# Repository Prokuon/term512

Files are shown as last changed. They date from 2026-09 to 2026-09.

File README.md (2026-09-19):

# TERM512: CardputerAdv Expansion Kit for AREA512 Firmware

TERM512 is a custom expansion kit for the CardputerAdv, tailored specifically for the [AREA512](https://github.com/engneer-hamachan/area512) firmware. It is designed to reshape the CardputerAdv into a cyberdeck that fully aligns with the visual aesthetics of AREA512, serving as the dedicated physical hardware platform for the project

Of course, this kit is essentially a stylized CapTFT expansion module, and adaptations for other firmwares are always welcome

The kit consists of the following components:

- **Custom-Designed CapTFT Enclosure**: Redesigns the top lid based on [CapTFT V2](https://github.com/Prokuon/CardputerADV_Cap_TFT_V2), and increases the maximum screen opening angle from 120° to 135°;
- **Protective Base**: Secured via two of the LEGO-compatible holes on the bottom of the CardputerAdv. It integrates two latches to lock the screen lid securely in place when closed, along with a lanyard hole;
- **Adjustable Kickstand**: Installed using the remaining two LEGO-compatible holes on the bottom. The hinge damping can be tuned via the adjustment bolt

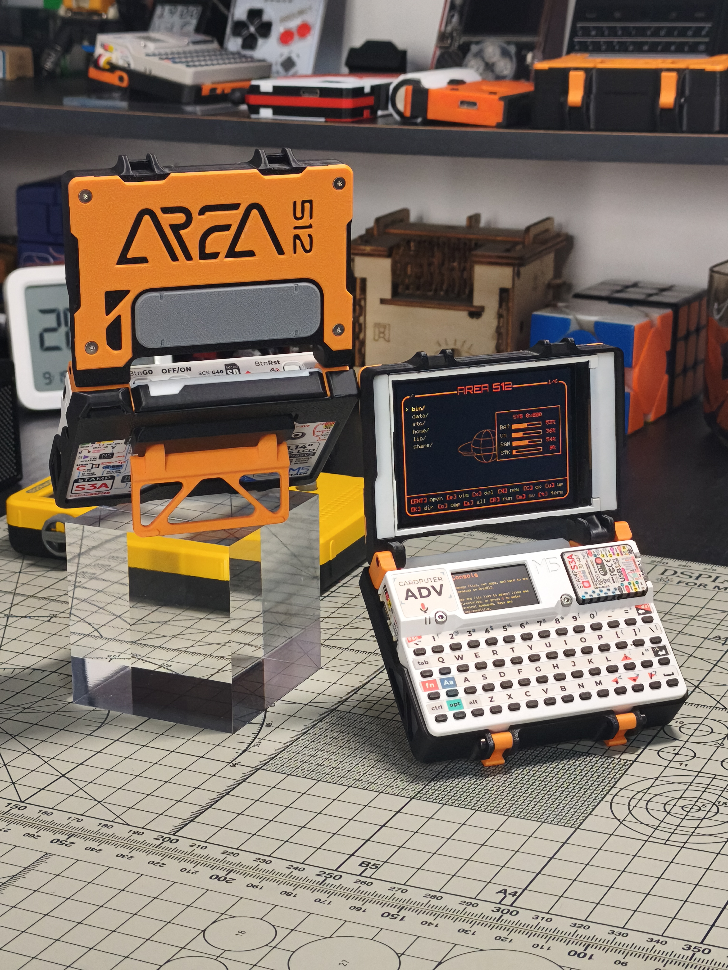
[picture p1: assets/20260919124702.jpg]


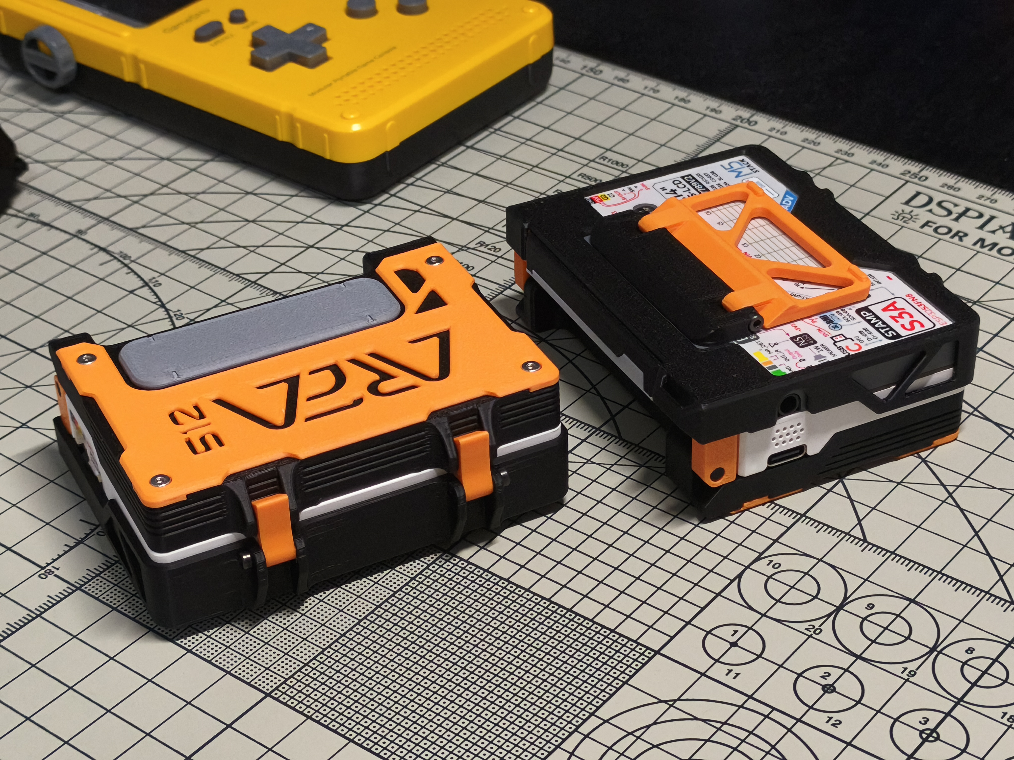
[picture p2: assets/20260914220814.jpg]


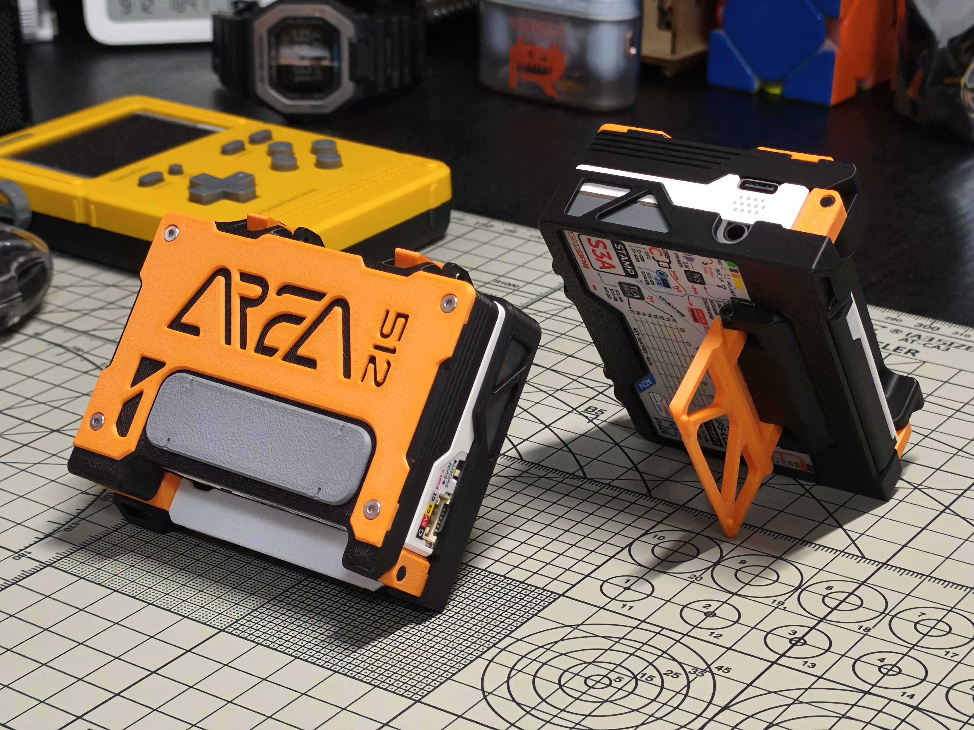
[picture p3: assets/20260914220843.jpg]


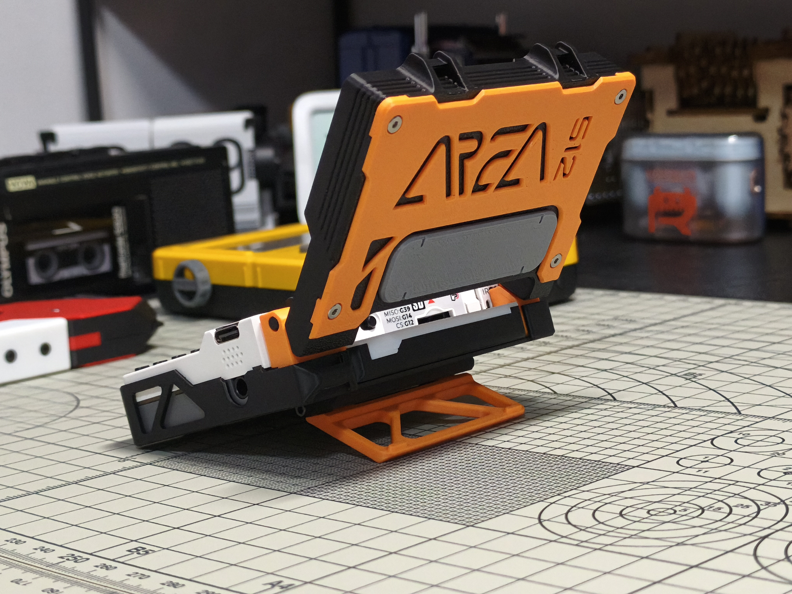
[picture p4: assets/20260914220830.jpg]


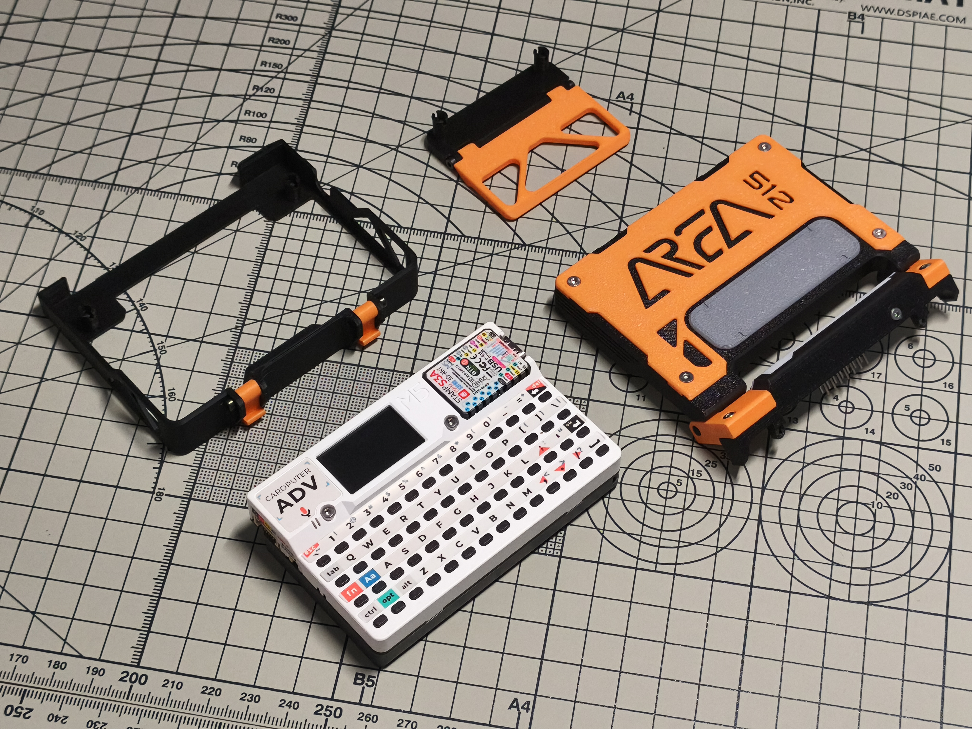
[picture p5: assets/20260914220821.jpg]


## BOM List

1. 3D printed shell D1
2. 3D printed shell C2
3. 3D printed shell C3
4. 3D printed shell D2
5. 3D printed shell D3
6. 3D printed shell R1
7. 3D printed shell L1
8. 3D printed shell S1
9. 3D printed shell C1
10. 3D printed shell B1
11. 3D printed shell T1 - 2 pieces
12. 3D printed shell K1
13. 3D printed shell K2
14. 2.8 inch ILI9341 display
15. M2x6 hex socket flat head bolts - 4 pieces
16. M2x5 hex socket cap bolts - 3 pieces
17. M2x10 hex socket cap bolts - 4 pieces
18. 2.54mm 2x7P dual-row straight pin header
19. Power supply module (AMS1117-3.3V)

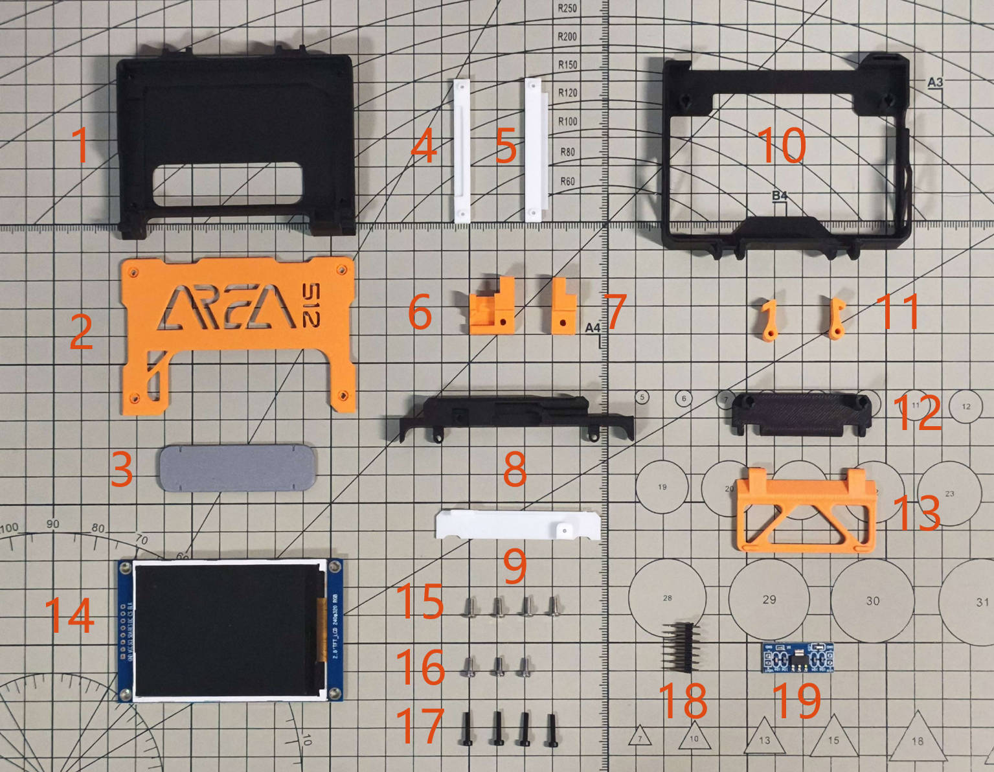
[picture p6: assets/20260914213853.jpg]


To improve the reproducibility of this project, two versions of the design are provided: TypeA fits displays with a blue PCB, and TypeB fits displays with a black PCB. Please print the corresponding model files based on your display selection

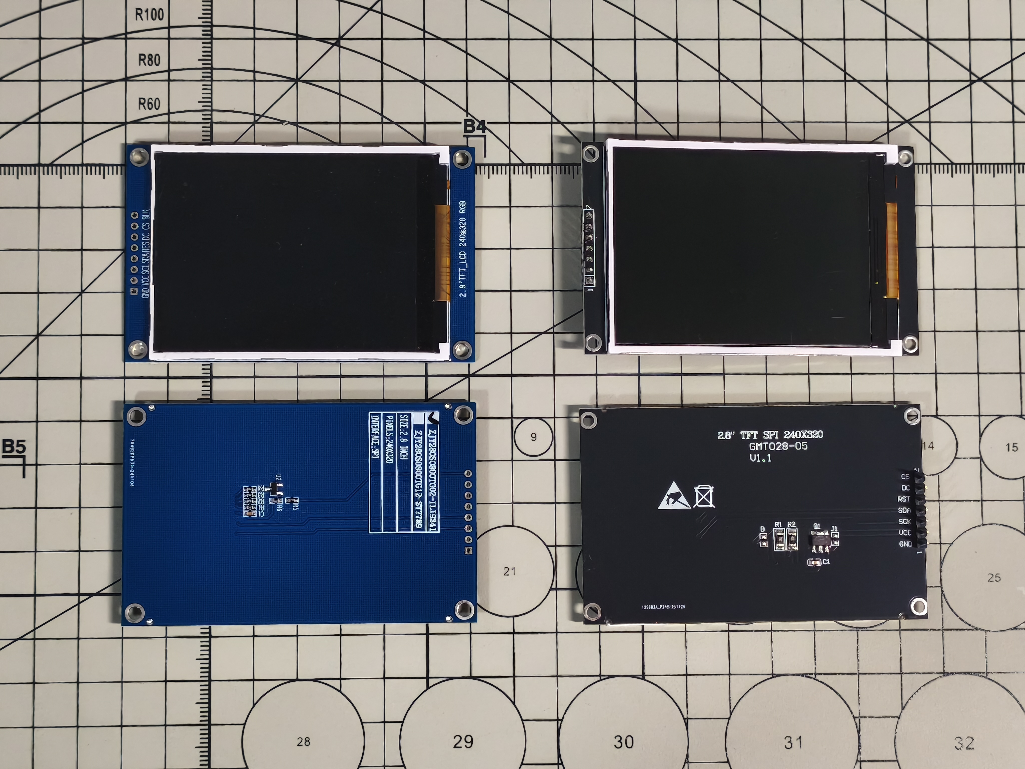
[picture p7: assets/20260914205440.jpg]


Blue PCB display reference image

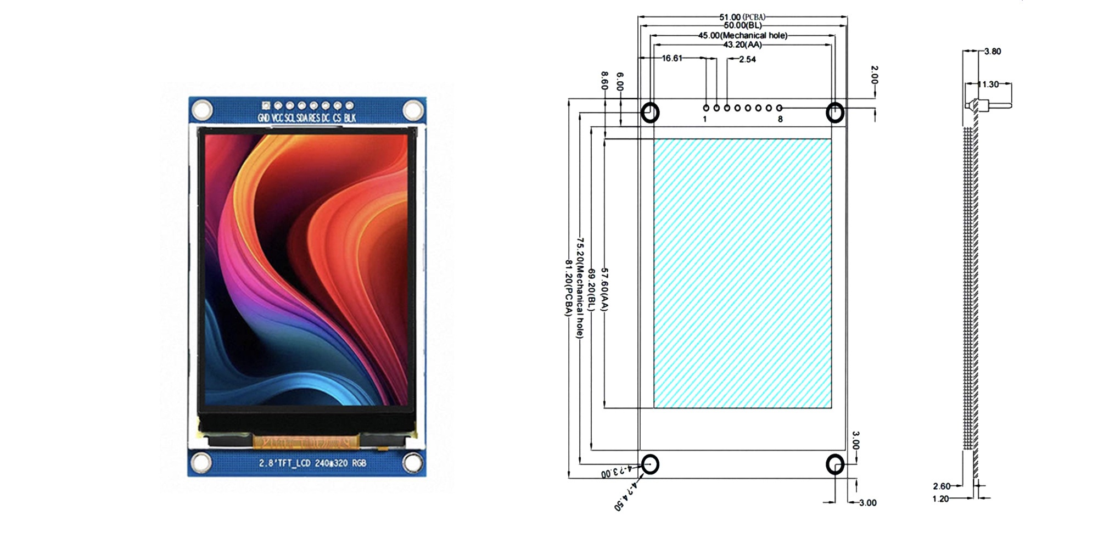
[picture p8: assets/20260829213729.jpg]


Black PCB display reference image

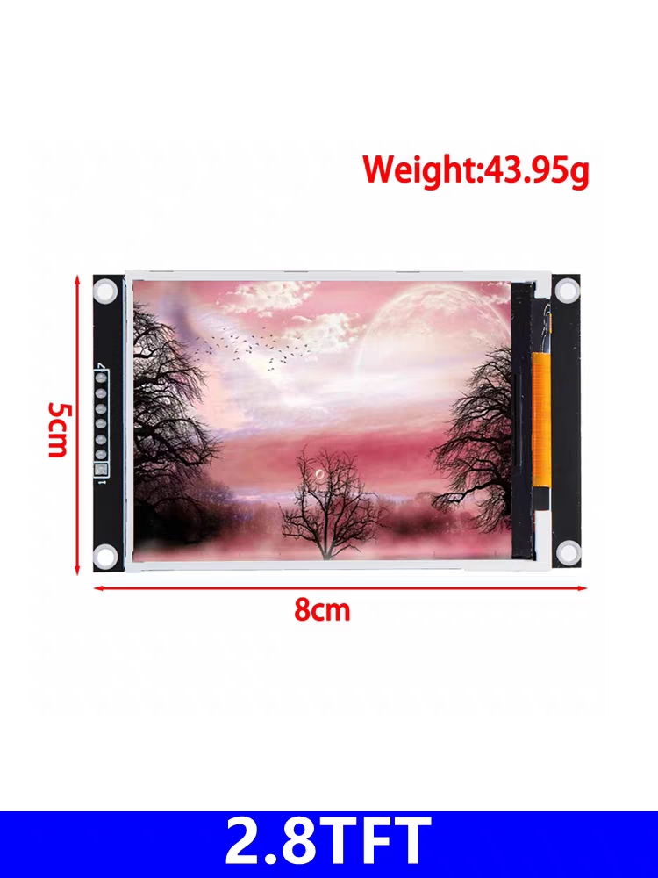
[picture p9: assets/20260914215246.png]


Power supply module reference image

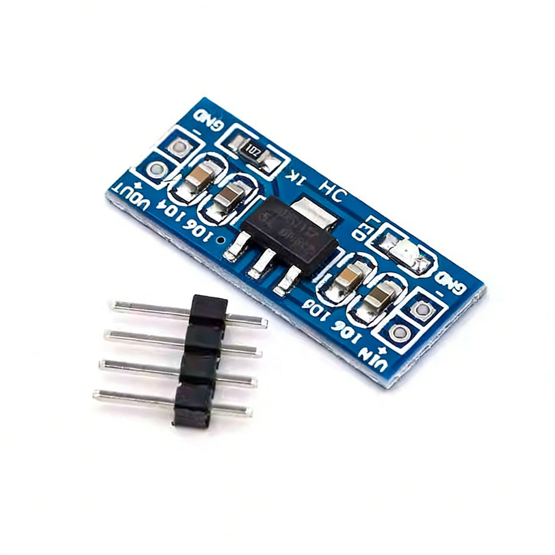
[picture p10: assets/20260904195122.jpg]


## Assembly Instructions

Attach the power supply module to the back of the display, and connect the display to the pin header using thin wires as shown in the diagram. It is recommended to use cable with an outer diameter of 0.65mm. For the wiring definition, please refer to the table below

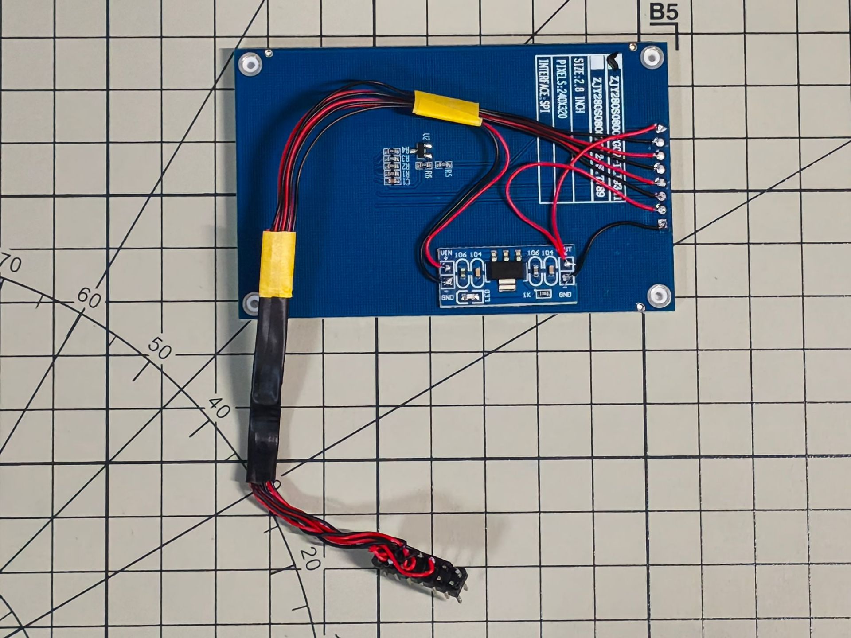
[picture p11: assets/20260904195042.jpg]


The black PCB display has one fewer pin than the blue PCB display (no BLK), while the definitions and order of the remaining pins are exactly the same as the blue PCB display. You can also refer to the table for wiring

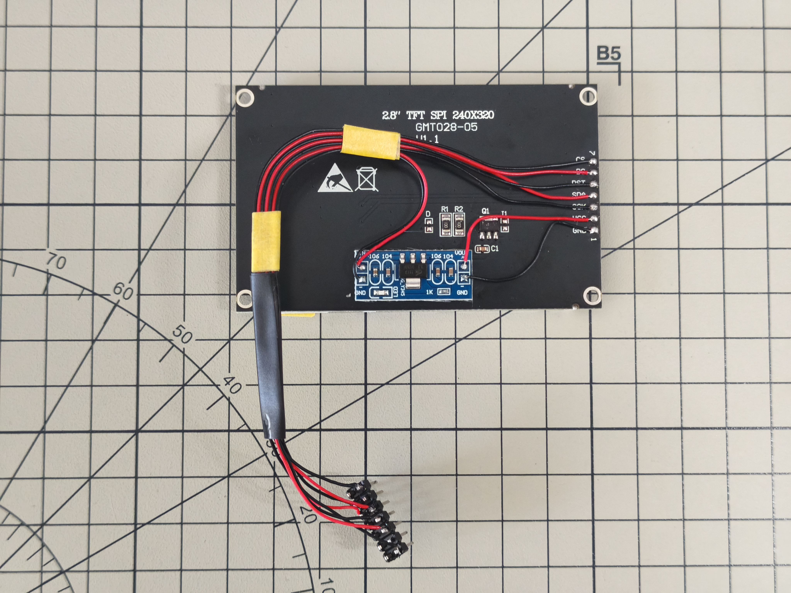
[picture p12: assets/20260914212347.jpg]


Display

| GND  | VCC  | SCL  | SDA  | RES  | DC | CS | BLK  |
| :--: | :--: | :--: | :--: | :--: | :--: | :--: | :--: |
| 1 | 2 | 3 | 4 | 5 | 6 | 7 | 8 |

Power supply module

| VIN  | VOUT |
| :--: | :--: |
| 10 | 2, 8 |
| GND  | GND  |
| 9 | 1 |

CardputerADV

| G3 | G4 | G6 | G40  | G14  | G39  | G5 |
| :--: | :--: | :--: | :--: | :--: | :--: | :--: |
| 5 | x | 6 | 3 | 4 | x | 7 |
| 5VIN | GND  | 5VOUT| SDA  | SCL  | G13  | G15  |
| x | 9 | 10 | x | x | x | x |

Install C2 and C3 onto D1. Note that C3 needs to be secured with glue

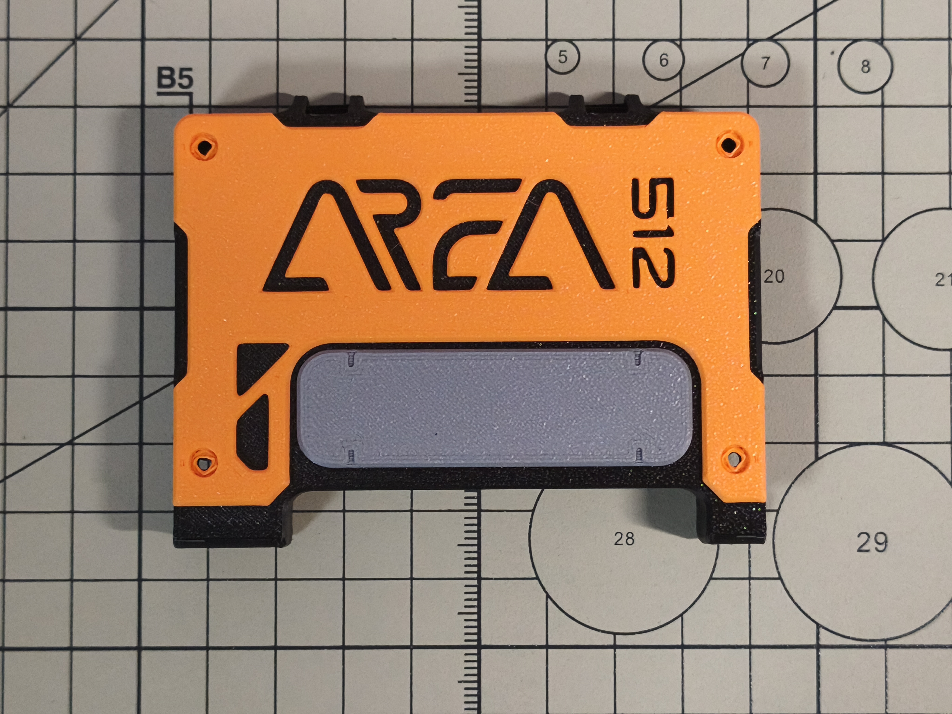
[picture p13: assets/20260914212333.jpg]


Install the display onto D1

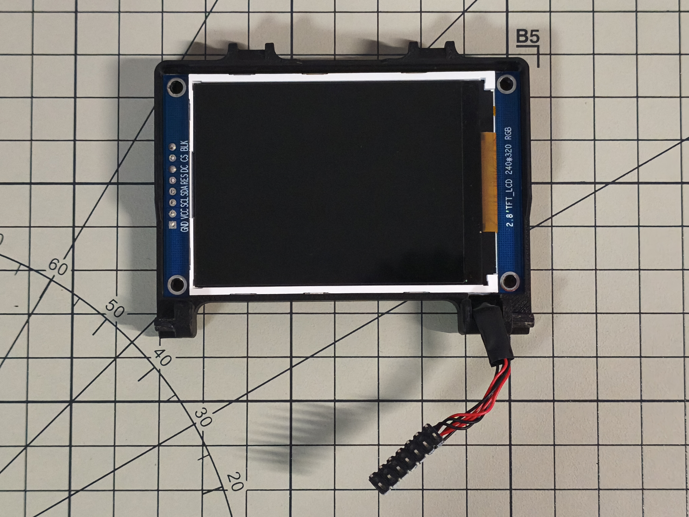
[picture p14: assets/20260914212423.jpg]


Use 4 M2x6 hex socket flat head bolts to install D2 and D3 onto D1

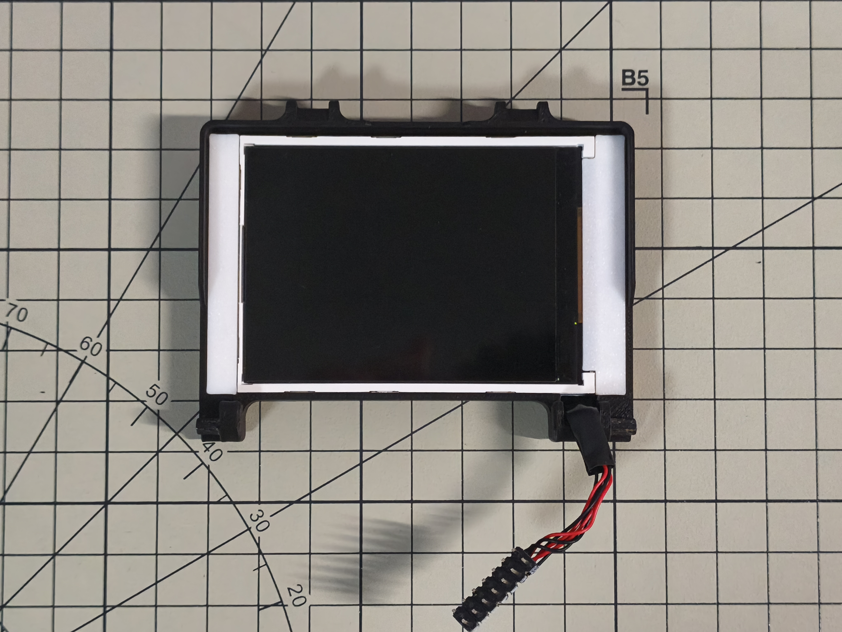
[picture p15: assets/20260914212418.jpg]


Install the pin header onto S1

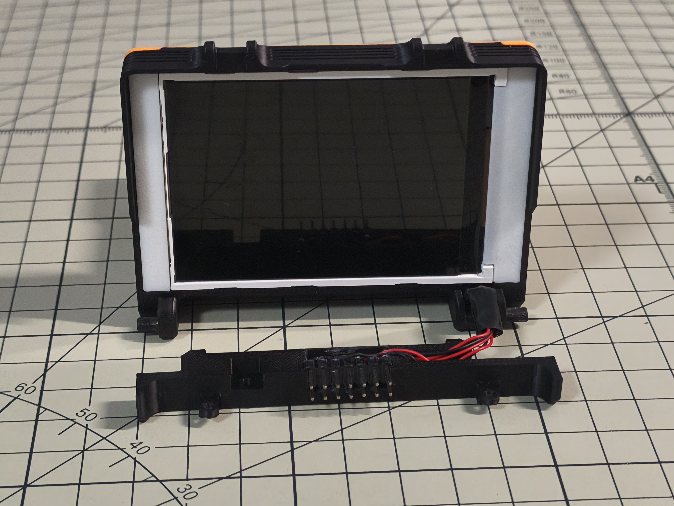
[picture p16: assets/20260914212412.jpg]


Use 1 M2x5 hex socket cap bolt to assemble C1 and S1

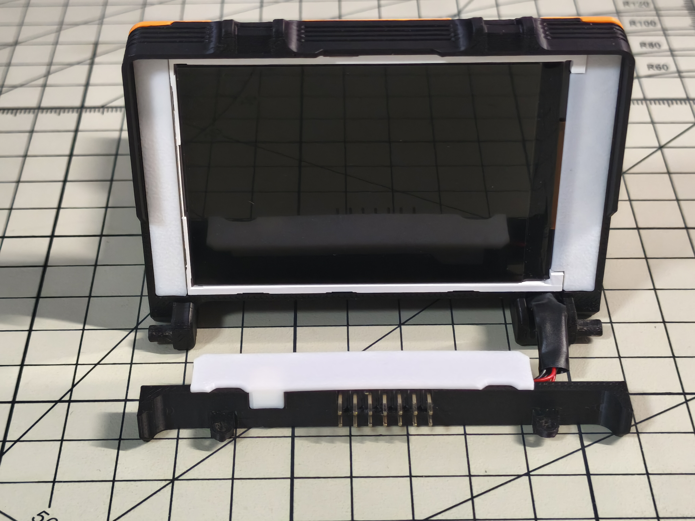
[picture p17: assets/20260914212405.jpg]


Install L1 and R1 onto D1, and use 2 M2x5 hex socket cap bolts to install L1 and R1 onto S1

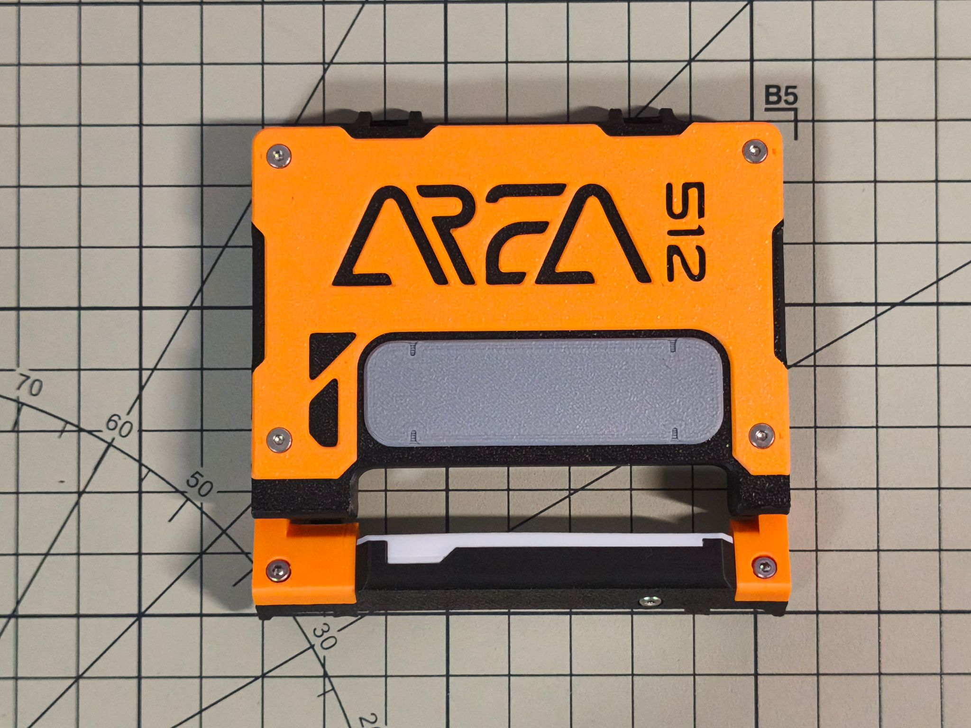
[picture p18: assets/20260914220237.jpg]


Use 2 M2x10 hex socket cap bolts to assemble T1 and B1

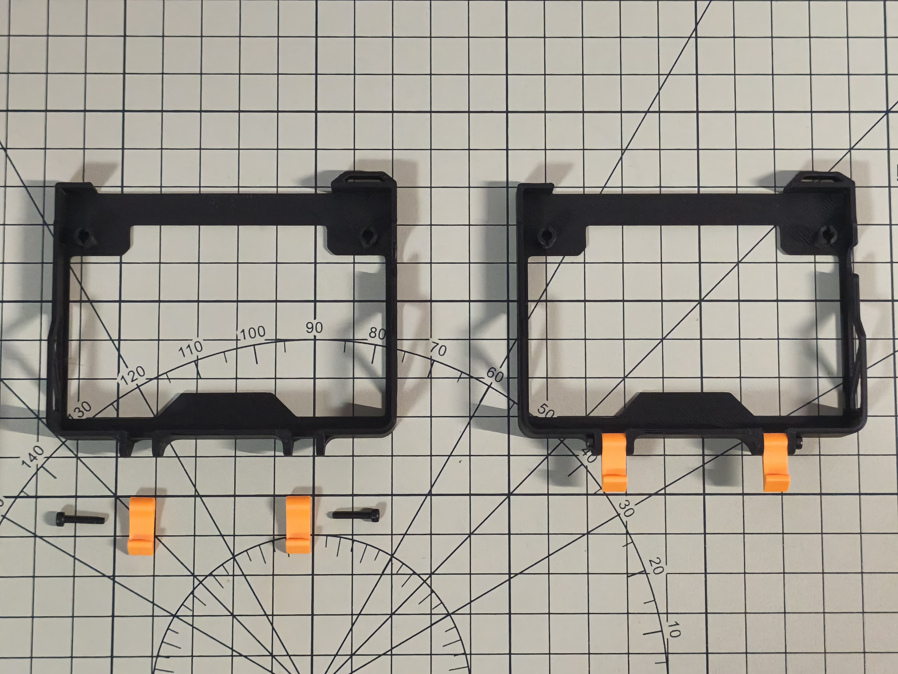
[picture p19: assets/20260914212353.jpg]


Use 2 M2x10 hex socket cap bolts to assemble K1 and K2

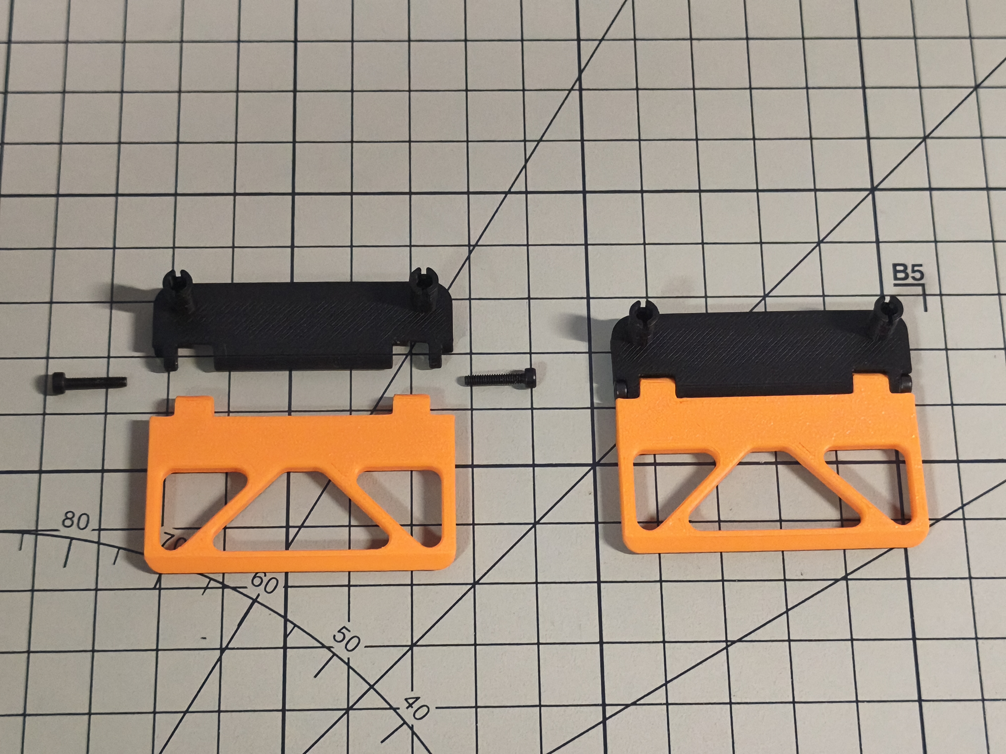
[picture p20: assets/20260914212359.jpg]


## Credits

- **[engneer-hamachan](https://github.com/engneer-hamachan)**: Thanks for adding official CapTFT support to the [AREA512](https://github.com/engneer-hamachan/area512) firmware. The design of TERM512 was directly inspired by AREA512's visual aesthetic and worldbuilding

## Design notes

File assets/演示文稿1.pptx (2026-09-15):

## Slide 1

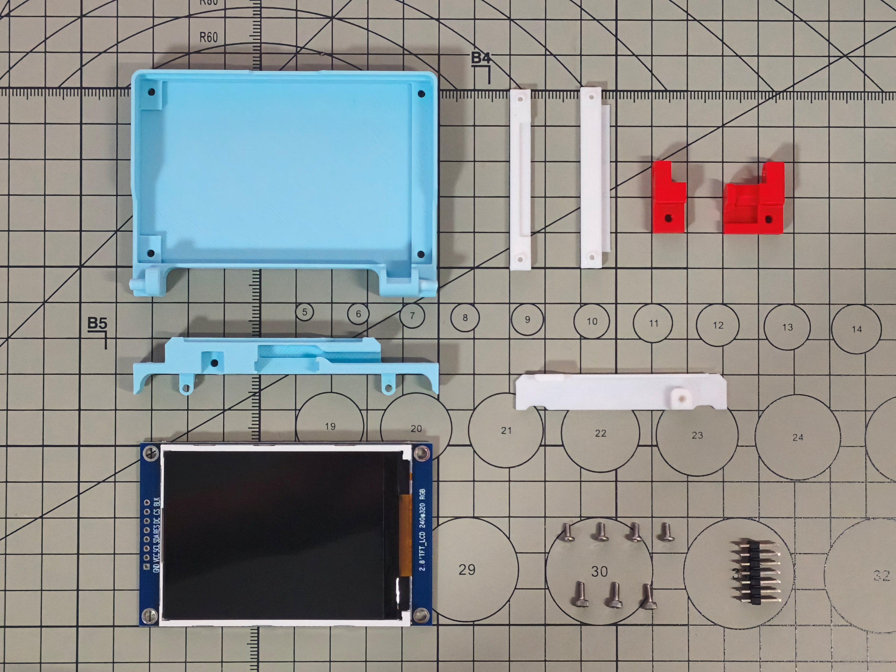
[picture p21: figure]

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
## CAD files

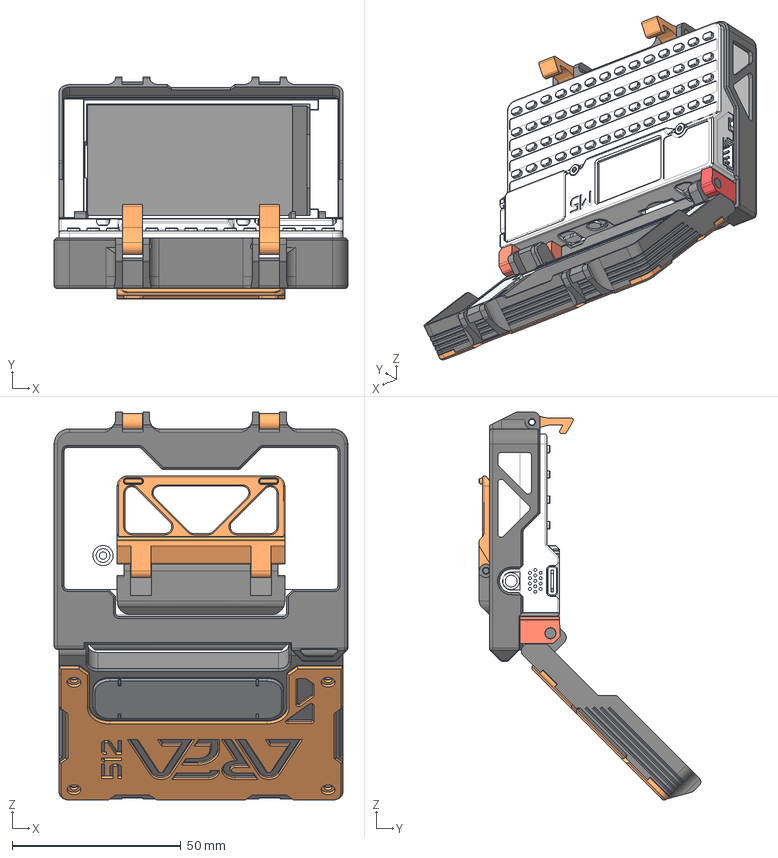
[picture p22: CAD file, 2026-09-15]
Model/TypeA/CapTFT_512_A.step
87.0 x 65.6 x 114.9 mm
CardputerADV
CaseS1
zl202-14_p2-54_l17-8_w5-08_h8-9
CaseD1
CaseD2
CaseR1
CaseL1
CaseC1
PCB
Frame (1)
LCD
Glass
CaseD3
CaseC2
CaseC3
CaseB1
CaseT1 x 2
CaseK1
CaseK2

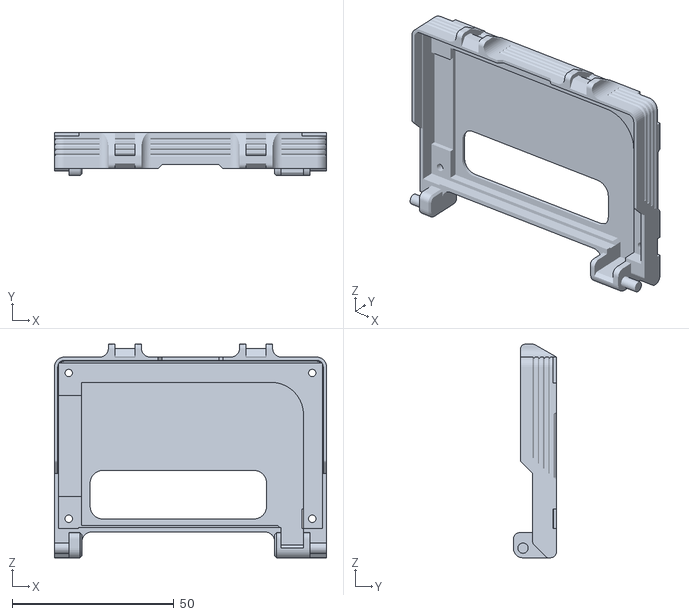
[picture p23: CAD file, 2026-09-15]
Model/TypeA/STL/CaseD1.stl
84.0 x 13.4 x 66.0

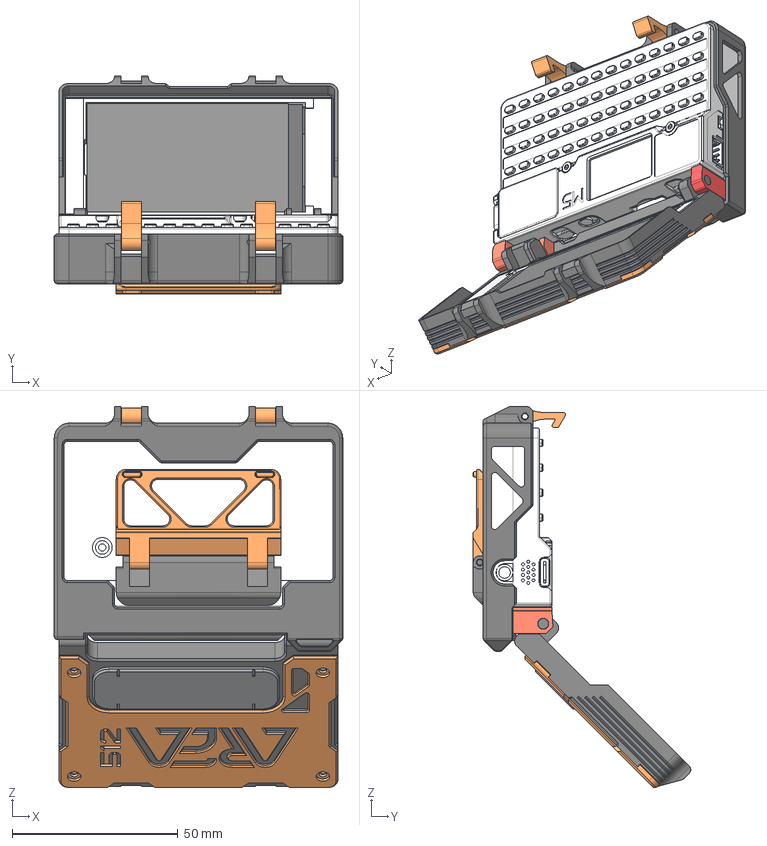
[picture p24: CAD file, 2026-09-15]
Model/TypeB/CapTFT_512_B.step
87.0 x 65.6 x 114.9 mm
CardputerADV
CaseS1
zl202-14_p2-54_l17-8_w5-08_h8-9
CaseD1
CaseD2
CaseR1
CaseL1
CaseC1
CaseD3
CaseC2
CaseC3
CaseB1
CaseT1 x 2
CaseK2
CaseK1
PCB
Frame (1)
LCD
Glass

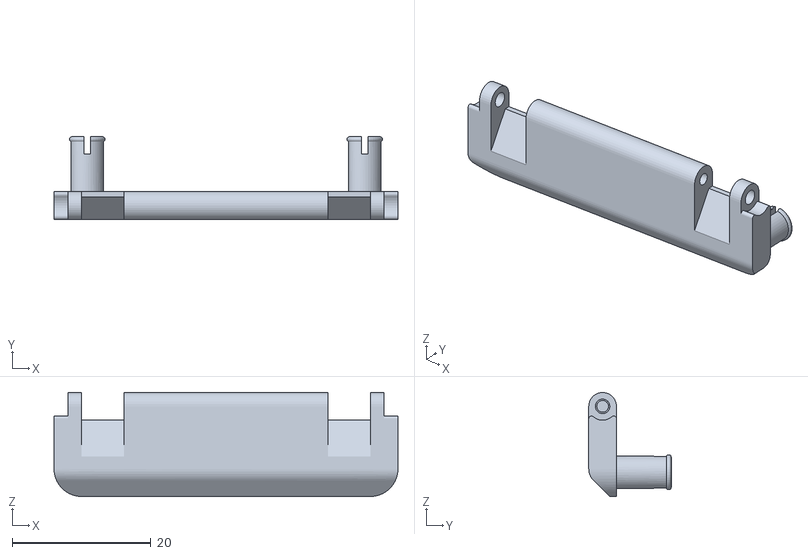
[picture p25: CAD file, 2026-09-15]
Model/TypeB/STL/CaseK1.stl
49.6 x 11.9 x 15.0

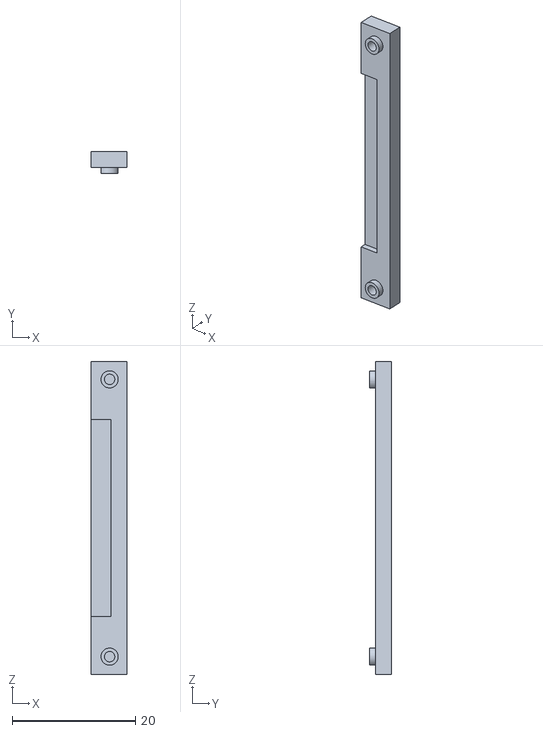
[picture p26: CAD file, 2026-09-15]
Model/TypeA/STL/CaseD2.stl
5.80 x 3.60 x 50.8

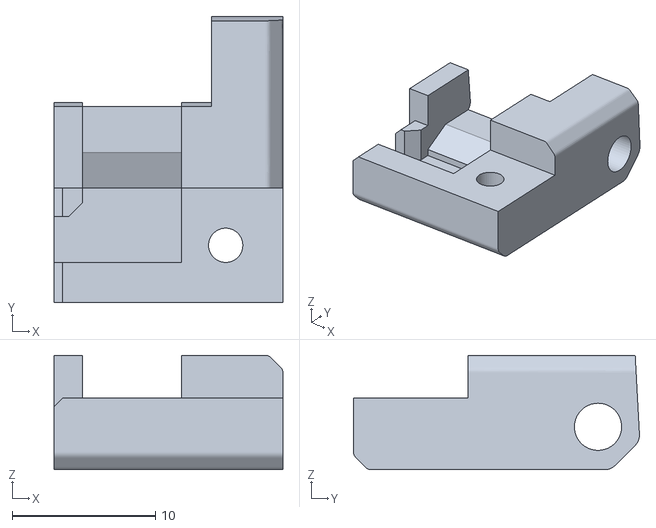
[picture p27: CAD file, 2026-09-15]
Model/TypeB/STL/CaseR1.stl
16.0 x 20.0 x 8.00

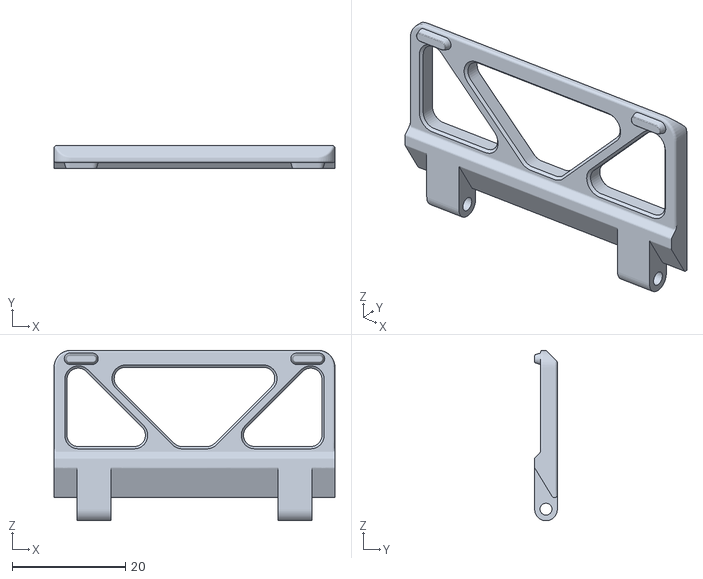
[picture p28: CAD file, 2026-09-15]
Model/TypeA/STL/CaseK2.stl
49.6 x 4.00 x 30.1

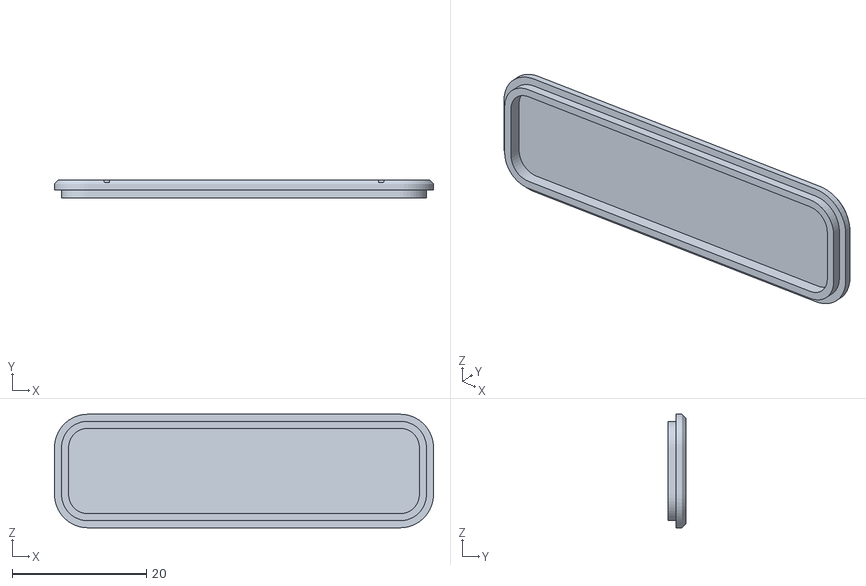
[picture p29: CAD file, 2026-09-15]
Model/TypeB/STL/CaseC3.stl
56.4 x 2.70 x 16.9

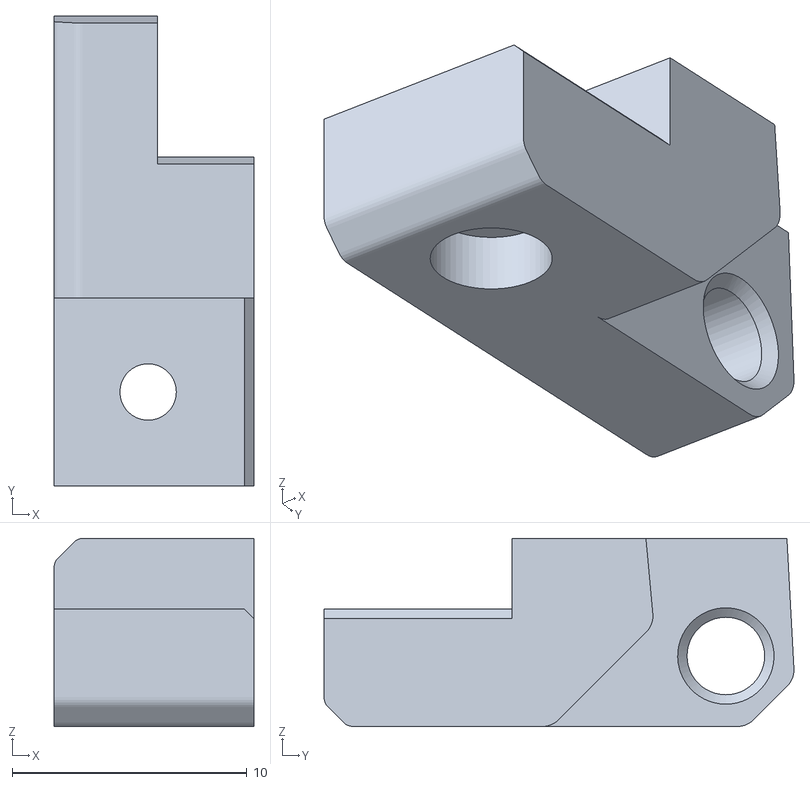
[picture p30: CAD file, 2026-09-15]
Model/TypeA/STL/CaseL1.stl
8.50 x 20.0 x 8.00

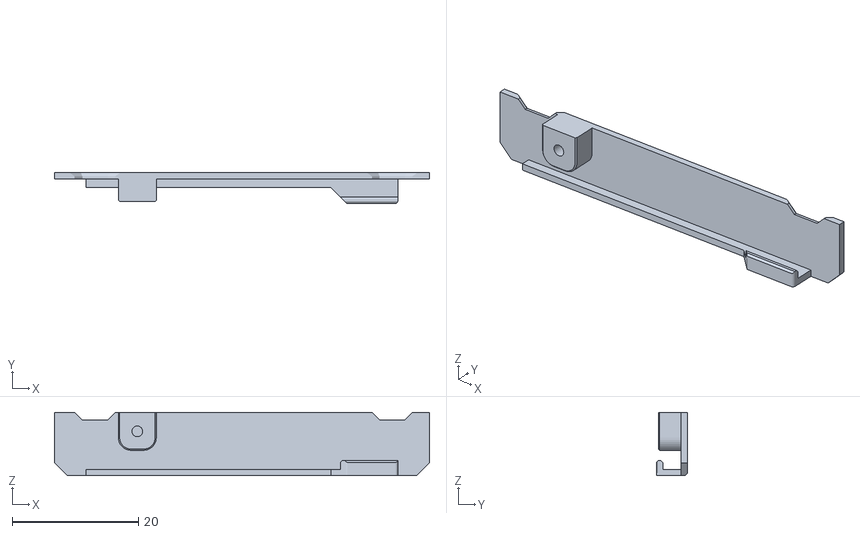
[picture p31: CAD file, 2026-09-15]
Model/TypeB/STL/CaseC1.stl
59.3 x 4.90 x 10.0

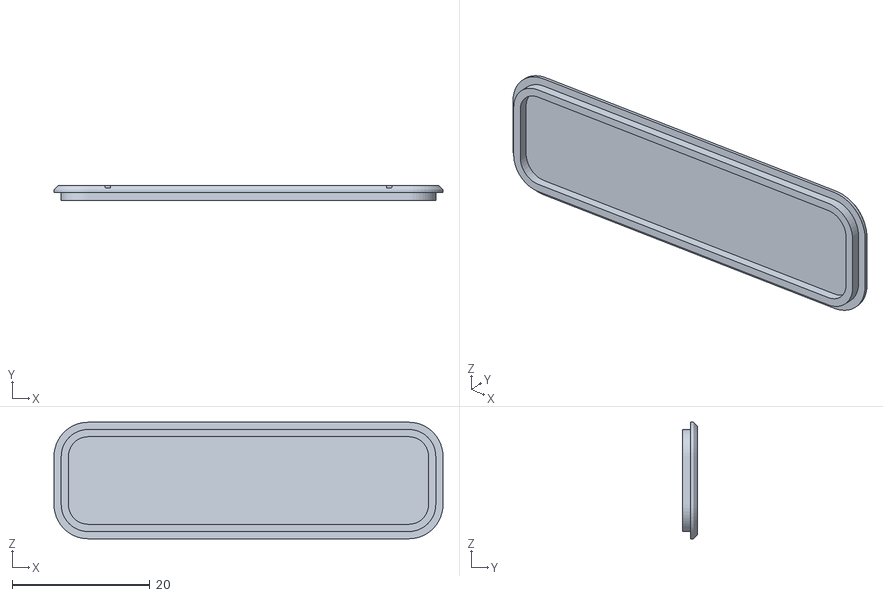
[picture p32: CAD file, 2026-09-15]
Model/TypeA/STL/CaseC3.stl
56.4 x 2.20 x 16.9

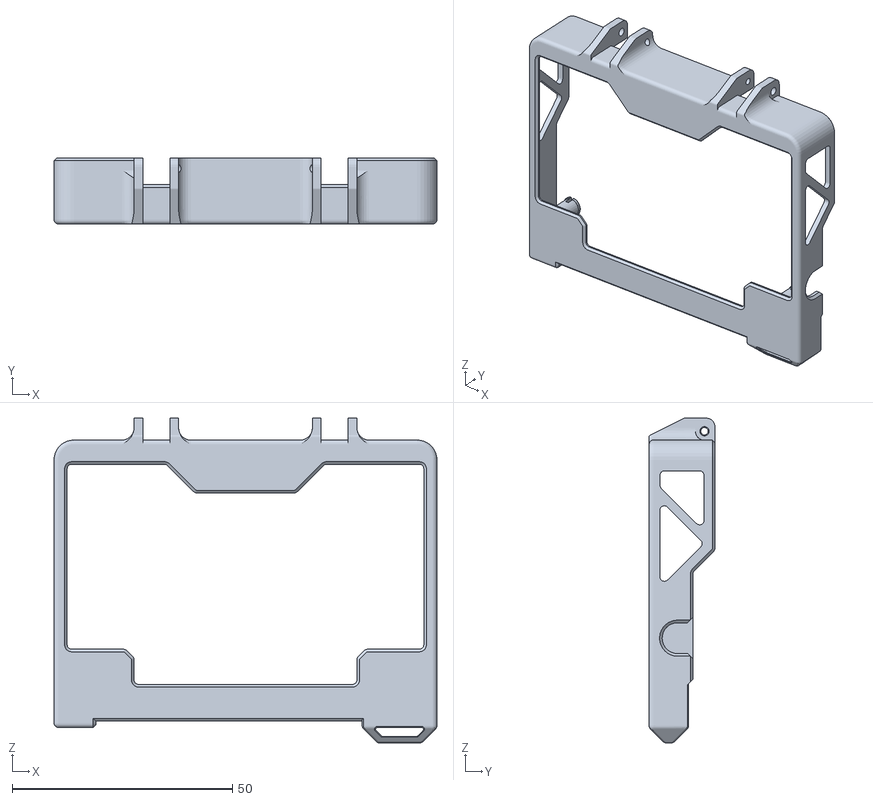
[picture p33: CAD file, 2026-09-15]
Model/TypeB/STL/CaseB1.stl
87.0 x 15.0 x 73.8

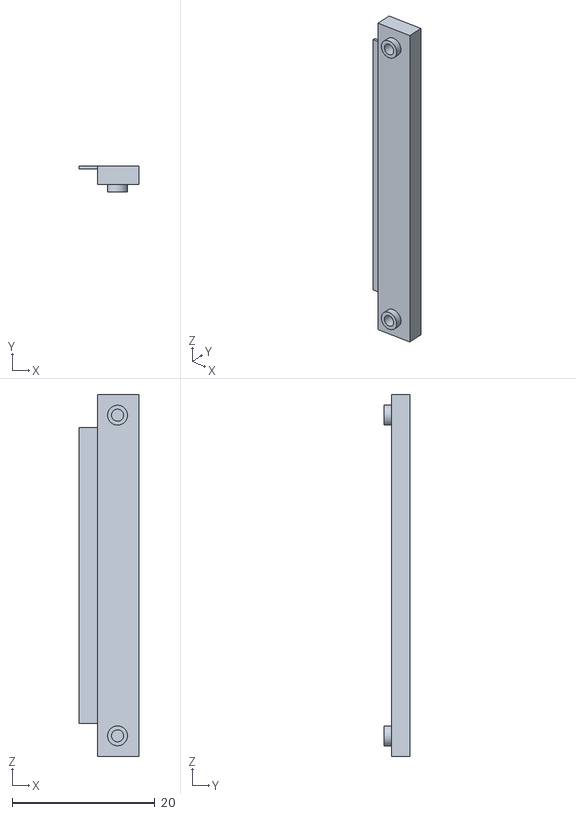
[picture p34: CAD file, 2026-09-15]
Model/TypeA/STL/CaseD3.stl
8.40 x 3.60 x 50.8

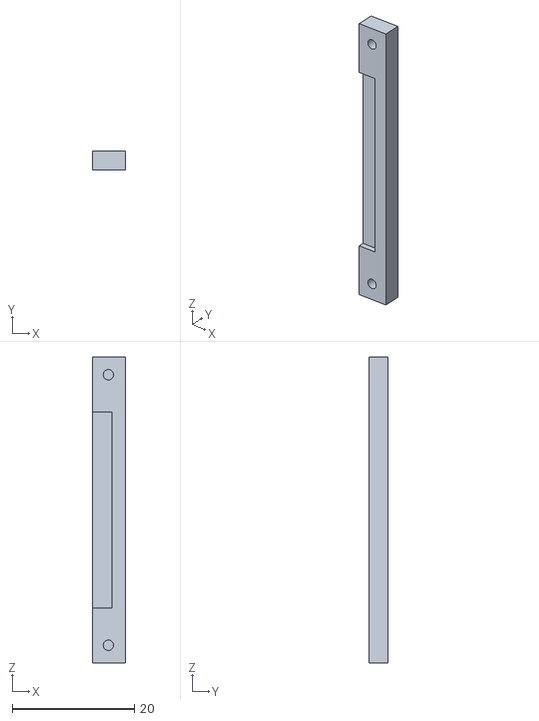
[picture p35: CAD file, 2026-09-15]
Model/TypeB/STL/CaseD2.stl
5.40 x 3.10 x 50.0

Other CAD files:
Model/TypeB/STL/CaseC2.stl
Model/TypeA/STL/CaseC2.stl
Model/TypeB/STL/CaseS1.stl
Model/TypeA/CapTFT_512_A.3mf
Model/TypeA/CapTFT_512_A.f3d
Model/TypeA/STL/CaseS1.stl
Model/TypeA/STL/CaseT1.stl
Model/TypeB/CapTFT_512_B.3mf
Model/TypeB/CapTFT_512_B.f3d
Model/TypeB/STL/CaseD1.stl
Model/TypeB/STL/CaseD3.stl
Model/TypeB/STL/CaseT1.stl
